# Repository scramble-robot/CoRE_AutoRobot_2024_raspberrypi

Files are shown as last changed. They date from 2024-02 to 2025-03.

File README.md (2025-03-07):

# SDカード

1. Raspberry Pi ImagerでRaspberry Pi OS Lite (64-bit,**bullseye**)をMicro SDに書き込む。Imagerの設定でユーザ名**pi**とパスワードを予め設定すること。
2. Micro SDに作成された"bootfs"ドライブ直下に`ssh`という名前のファイルを配置してSSHを有効化する。
3. OS起動後、本レポジトリの`ros2_ws`及び`service`ディレクトリをホームディレクトリ(`/home/pi/`)にコピーする。

# C620とのCAN通信

MCP2515を用いてSPIからCANを制御

- (参考) [RaspberryPiとMCP2515でCAN通信をやってみる](https://qiita.com/h-kiyo/items/d8583af13768ad67bcd0)

## ハードウェア
1Mbpsの通信を行うために、水晶振動子を**16MHz**に交換すること

## CAN-BUSの有効化
1. `/boot/config.txt`を編集してSPIとMCP2515を有効化する
    ```bash
    sudo vi /boot/config.txt
    ```

    ```
    # Uncomment some or all of these to enable the optional hardware interfaces
    #dtparam=i2c_arm=on
    #dtparam=i2s=on
    dtparam=spi=on

    # MCP2515
    dtparam=spi=on
    dtoverlay=mcp2515-can0,oscillator=16000000,interrupt=25
    dtoverlay=spi-bcm2835-overlay
    ```

2. 初期化できているか確認
    ```
    dmesg | grep mcp251x
    ```

## can-utilsのインストール
```bash
sudo apt install can-utils
```

## 通信テスト

1Mbpsでlink up

```bash
sudo ip link set can0 type can bitrate 1000000 loopback off
sudo ip link set can0 up
sudo ifconfig can0 txqueuelen 1000
sudo ifconfig
```

### 受信テスト
```bash
candump can0
```

C620と通信できていると、以下のようなデータが受信される。
```text
  can0  201   [8]  0E 16 00 00 FF FD 21 00
  can0  201   [8]  0E 16 00 00 FF FD 21 00
  can0  201   [8]  0E 16 00 00 FF BE 21 00
  can0  201   [8]  0E 16 00 00 FF FD 21 00
  can0  201   [8]  0E 16 00 00 00 3D 21 00
```

### 送信
モータ回るはず
```bash
cansend can0 200#0200000000000000
```

## systemdによるCANバスの自動有効化

1. systemdの設定
    ```bash
    sudo vi /etc/systemd/network/80-can.network
    ```

    ```text
    [Match]
    Name=can*

    [CAN]
    BitRate=1000000
    ```

    設定後、以下コマンド実行
    ```bash
    sudo systemctl enable systemd-networkd
    sudo systemctl start systemd-networkd
    ```

2. txqueuelenの自動設定
    ```bash
    sudo vi /etc/udev/rules.d/71-can-txqueuelen.rules
    ```

    ```
    SUBSYSTEM=="net", ACTION=="add|change", KERNEL=="can*", ATTR{tx_queue_len}="1000"
    ```

3. 再起動後、`ifconfig`でlink upしていることを確認

    ```
    can0: flags=193<UP,RUNNING,NOARP>  mtu 16
            unspec 00-00-00-00-00-00-00-00-00-00-00-00-00-00-00-00  txqueuelen 1000  (UNSPEC)
            RX packets 0  bytes 0 (0.0 B)
            RX errors 0  dropped 0  overruns 0  frame 0
            TX packets 0  bytes 0 (0.0 B)
            TX errors 0  dropped 0 overruns 0  carrier 0  collisions 0
    ```

## Pythonからの制御

```bash
pip install python-can
```

```python
import can
import struct
import time

bus = can.interface.Bus(bustype="socketcan", channel="can0", bitrate=1000000)

def set_current(bus, currents):
    d = [0]*8
    raw_array = [0]*4
    for i in range(4):
        v = int(round(currents[i]/20 * 16384))
        v = min(v, 16384)
        v = max(v, -16384)
        raw_array[i] = v
    b = struct.pack('>4h', *raw_array)
    msg = can.Message(arbitration_id=0x200, is_extended_id=False, data=b)
    bus.send(msg)

def parse_c620_data(msg: can.Message):
    data = struct.unpack('>hhhbb', msg.data)
    degree = data[0]/ 8192 * 360
    rpm = data[1]
    current = data[2]/16384*20
    temperature = data[3]
    return degree, rpm, current, temperature

def can_receive_callback(msg: can.Message) -> None:
    #print(msg)
    if msg.arbitration_id >= 0x201 and msg.arbitration_id < 0x204:
        degree, rpm, current, temperature = parse_c620_data(msg)
        print(f'{degree:.1f}\t{rpm:+5d}\t{current:.1f}\t{temperature:2d}')

notifier = can.Notifier(bus, [can_receive_callback])

set_current(bus, [1, -1, 0, 0])
time.sleep(1)

set_current(bus, [-1, 1, 0, 0])
time.sleep(1)

for i in range(4):
    set_current(bus, [0, 0, 0, 0])
    time.sleep(1)

notifier.stop()
bus.shutdown()
```

# サーボモータ
## ハードウェア
- 信号線はGPIO17に接続
- サーボモータの5Vは外部電源から取ること

## requirements
```bash
sudo apt install -y pigpio python3-pigpio
sudo pigpiod
sudo systemctl enable pigpiod
```

## 動作確認

```python
import pigpio

output_pin = 12 # 12 or 13

def setServoDegree(pi, output_pin, degree):
    min_width = 500
    max_width = 2500
    deg_range = 270
    output = degree / deg_range
    output *= max_width - min_width
    output += min_width
    output = int(output)
    pi.set_servo_pulsewidth(output_pin, output)

pi = pigpio.pi()
pi.set_mode(output_pin, pigpio.OUTPUT)
pi.set_servo_pulsewidth(output_pin, 0)

while True:
    print("input Duty Cyle (0 - 270)")
    degree = float(input())
    setServoDegree(pi, output_pin, degree)
```

# ROS2のインストール

Raspbian OS用の、[非公式のdebパッケージ](https://github.com/Ar-Ray-code/rpi-bullseye-ros2)を使ってインストールする

```bash
wget https://github.com/Ar-Ray-code/rpi-bullseye-ros2/releases/download/ros2-0.3.1/ros-humble-desktop-0.3.1_20221218_arm64.deb
sudo apt install ./ros-humble-desktop-0.3.1_20221218_arm64.deb
sudo pip install vcstool colcon-common-extensions

echo "source /opt/ros/humble/setup.bash" >> ~/.bashrc
source ~/.bashrc
```

## ROS2パッケージのビルド
```
cd ~/ros2_ws
colcon build --symlink-install
source install/local_setup.bash
echo "source ~/ros2_ws/install/setup.bash" >> ~/.bashrc
```

## ROS2ノードの実行
```bash
ros2 launch scramble_auto_robot hardware.launch.py
```
- この段階で下記のようなエラーが出る場合は，Raspberry piのOSのバージョンが誤っているためSDカード作成からやり直す必要がある．OSのバージョンはbullseyeを指定すること（何も指定しないと最新版のbookwormがインストールされる）
```[INFO] [launch]: All log files can be found below /home/pi/.ros/log/2024-02-11-18-34-23-302048-raspberrypi-2602
[INFO] [launch]: Default logging verbosity is set to INFO
[ERROR] [launch]: Caught exception in launch (see debug for traceback): Caught exception when trying to load file of format [py]: No module named 'rclpy._rclpy_pybind11'
The C extension '/opt/ros/humble/lib/python3.9/site-packages/_rclpy_pybind11.cpython-311-aarch64-linux-gnu.so' isn't present on the system. Please refer to 'https://docs.ros.org/en/humble/Guides/Installation-Troubleshooting.html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' for possible solutions
```

## 確認
```bash
ros2 topic pub /can_node/c620_0/target_current std_msgs/Float64 "{data: 1.0}"
ros2 topic pub /can_node/c620_0/target_current std_msgs/Float64 "{data: 0.0}"
ros2 topic pub /servo0/degree std_msgs/Float64 "{data: 0}"
ros2 topic pub /servo1/degree std_msgs/Float64 "{data: 0}"
ros2 topic echo /can_node/c620_0/rpm
```

## 自動起動
```bash
sudo ln -s /home/pi/service/scramble_auto_robot_ros2.service /etc/systemd/system
chmod 755 /home/pi/service/ros2_launch.sh
sudo systemctl enable scramble_auto_robot_ros2.service
sudo systemctl start scramble_auto_robot_ros2.service
systemctl status scramble_auto_robot_ros2.service
```

# 起動オプションの変更
1. ターミナルで`sudo raspi-config`を実行
2. "1. System Options"を選択
3. "S6 Network as Boot"でネットワーク確率までBootを待つように設定
4. "S5 Boot / Auto Login"で"Console Autologin"を選択

# SDカードのRead only化
SDカードへの書き込み中に電源を抜くとSDカードが壊れる可能性があるので、read-onlyに設定する。

参考: [Raspberry Pi で Overlay File System (read-only file system) を試す](https://qiita.com/nanbuwks/items/d5d0cfc5f94177515a6a)

1. ターミナルで`sudo raspi-config`を実行
2. "4 Performance Options Configure performance settings"
3. "P3 Overlay File System Enable/disable read-only file system"
4. 有効化して再起動

# その他
- ros2_launch.shにて`ROS_DOMAIN_ID=0`に設定しています。
- デフォルトの設定ではIPアドレスの割当はDHCPで行われます。

# Third-party license
本手順で作成した場合、以下のサードパーティ製ソフトウェアがインストールされます。
(本レポジトリに直接は含まれていません)

- Raspbian OS
- ROS2 Humble
- [rpi-bullseye-ros2](https://github.com/Ar-Ray-code/rpi-bullseye-ros2/blob/main/LICENSE) (MIT License)
- [python-can](https://pypi.org/project/python-can/) (LGPL v3)
- [pigpio](https://github.com/joan2937/pigpio/blob/master/UNLICENCE) (Unlicense)

デバッグ用
- [can-utils](https://github.com/linux-can/can-utils/tree/master/LICENSES)

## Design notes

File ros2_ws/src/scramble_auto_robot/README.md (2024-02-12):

# CoRE Automatic Robot Hardware Package

This package contains a two ros2 nodes which control hardware components

## can_node
#### Subscriber
- `/can_node/motor0/target_current` \
  Data type: Float64 \
  Data range: 0 to 20 [A]

- `/can_node/motor1/target_current` \
  Data type: Float64 \
  Data range: 0 to 20 [A]

#### Publisher
- `/can_node/motor0/rpm` \
  Data type: Float64

- `/can_node/motor1/rpm` \
  Data type: Float64

## servo_node
#### Subscriber
- `/servo0/degree` \
  Data type: Float64 \
  Data range: 0 to 270
- `/servo1/degree` \
  Data type: Float64 \
  Data range: 0 to 270

## gpio_node
#### Publisher
- `/gpio_node/in0` \
  Data type: Bool
- `/gpio_node/in1` \
  Data type: Bool
- `/gpio_node/in2` \
  Data type: Bool
- `/gpio_node/in3` \
  Data type: Bool

# launch
```bash
ros2 launch scramble_auto_robot hardware.launch.py
```

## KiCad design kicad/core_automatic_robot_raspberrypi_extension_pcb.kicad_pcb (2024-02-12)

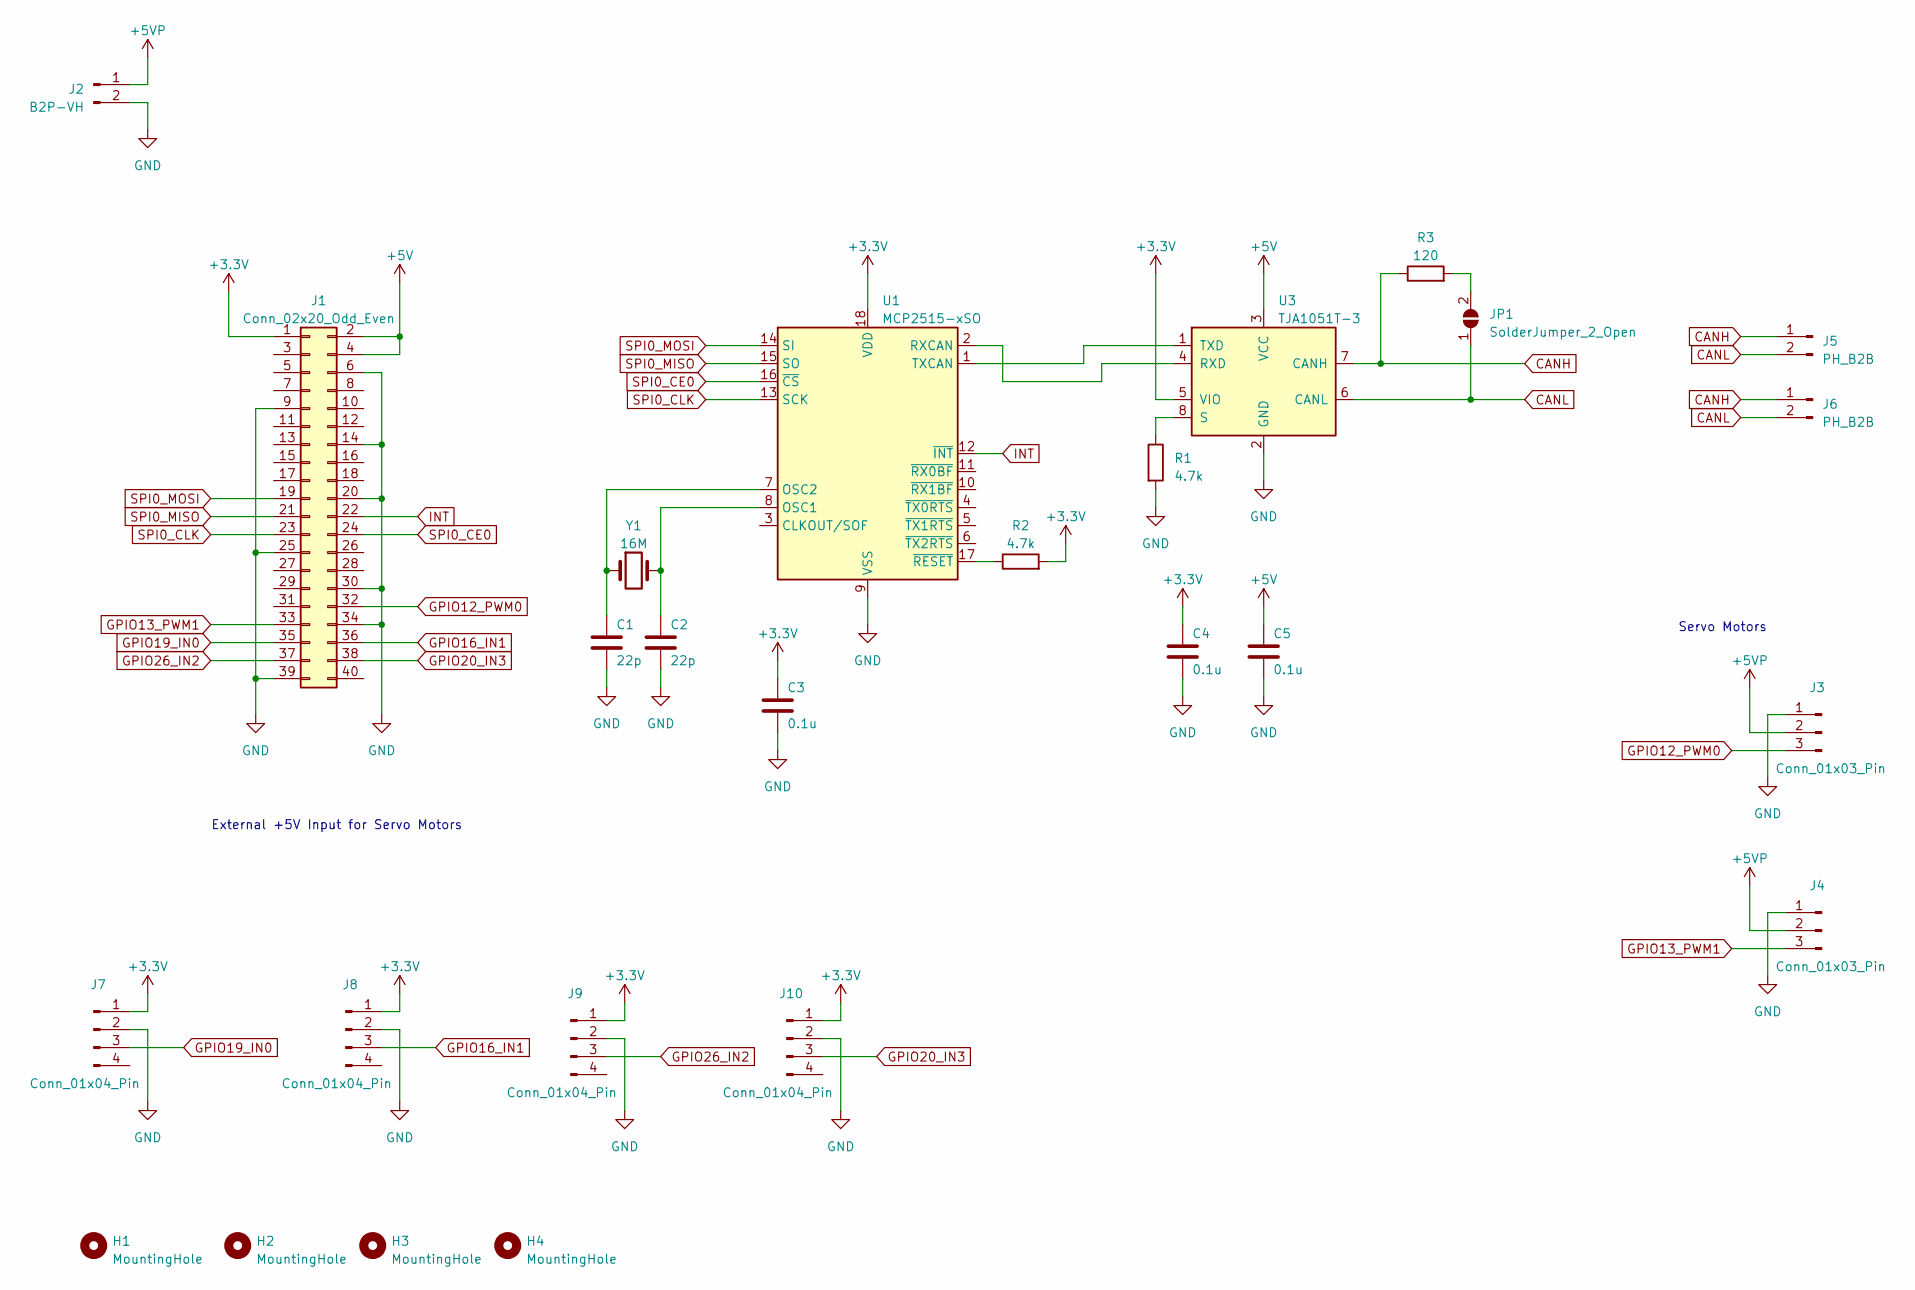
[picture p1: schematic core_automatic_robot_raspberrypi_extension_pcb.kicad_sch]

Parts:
C1, C2: 22p; C_0603_1608Metric_Pad1.08x0.95mm_HandSolder
C3, C4, C5: 0.1u; C_0603_1608Metric_Pad1.08x0.95mm_HandSolder
H1, H2, H3, H4: MountingHole; MountingHole_3.2mm_M3
J1: Conn_02x20_Odd_Even; PinHeader_2x20_P2.54mm_Vertical
J2: B2P-VH; JST_VH_B2P-VH-B_1x02_P3.96mm_Vertical
J3, J4: Conn_01x03_Pin; PinHeader_1x03_P2.54mm_Horizontal
J5, J6: PH_B2B; JST_PH_B2B-PH-K_1x02_P2.00mm_Vertical
J7, J8, J9, J10: Conn_01x04_Pin; JST_XH_B4B-XH-A_1x04_P2.50mm_Vertical
JP1: SolderJumper_2_Open; SolderJumper-2_P1.3mm_Open_Pad1.0x1.5mm
R1, R2: 4.7k; R_0603_1608Metric_Pad0.98x0.95mm_HandSolder
R3: 120; R_0603_1608Metric_Pad0.98x0.95mm_HandSolder
U1: MCP2515-xSO; SOIC-18W_7.5x11.6mm_P1.27mm
U3: TJA1051T-3; SOIC-8_3.9x4.9mm_P1.27mm
Y1: 16M; Crystal_HC49-U_Vertical

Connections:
+3.3V: C3.1, C4.1, J1.1, J7.1, J8.1, J9.1, J10.1, R2.2, U1.18 (VDD), U3.5 (VIO)
+5V: C5.1, J1.2, J1.4, U3.3 (VCC)
+5VP: J2.1, J3.2, J4.2
CANH: J5.1, J6.1, R3.1, U3.7 (CANH)
CANL: J5.2, J6.2, JP1.1 (A), U3.6 (CANL)
GND: C1.2, C2.2, C3.2, C4.2, C5.2, J1.6, J1.9, J1.14, J1.20, J1.25, J1.30, J1.34, J1.39, J2.2, J3.1, J4.1, J7.2, J8.2, J9.2, J10.2, R1.2, U1.9 (VSS), U3.2 (GND)
GPIO12_PWM0: J1.32, J3.3
GPIO13_PWM1: J1.33, J4.3
GPIO16_IN1: J1.36, J8.3
GPIO19_IN0: J1.35, J7.3
GPIO20_IN3: J1.38, J10.3
GPIO26_IN2: J1.37, J9.3
INT: J1.22, U1.12 (~INT)
unnamed: JP1.2 (B), R3.2
unnamed: C2.1, U1.8 (OSC1), Y1.2
unnamed: C1.1, U1.7 (OSC2), Y1.1
unnamed: U1.2 (RXCAN), U3.4 (RXD)
unnamed: U1.1 (TXCAN), U3.1 (TXD)
unnamed: R2.1, U1.17 (~RESET)
unnamed: R1.1, U3.8 (S)
SPI0_CE0: J1.24, U1.16 (~CS)
SPI0_CLK: J1.23, U1.13 (SCK)
SPI0_MISO: J1.21, U1.15 (SO)
SPI0_MOSI: J1.19, U1.14 (SI)

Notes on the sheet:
Servo Motors
External +5V Input for Servo Motors

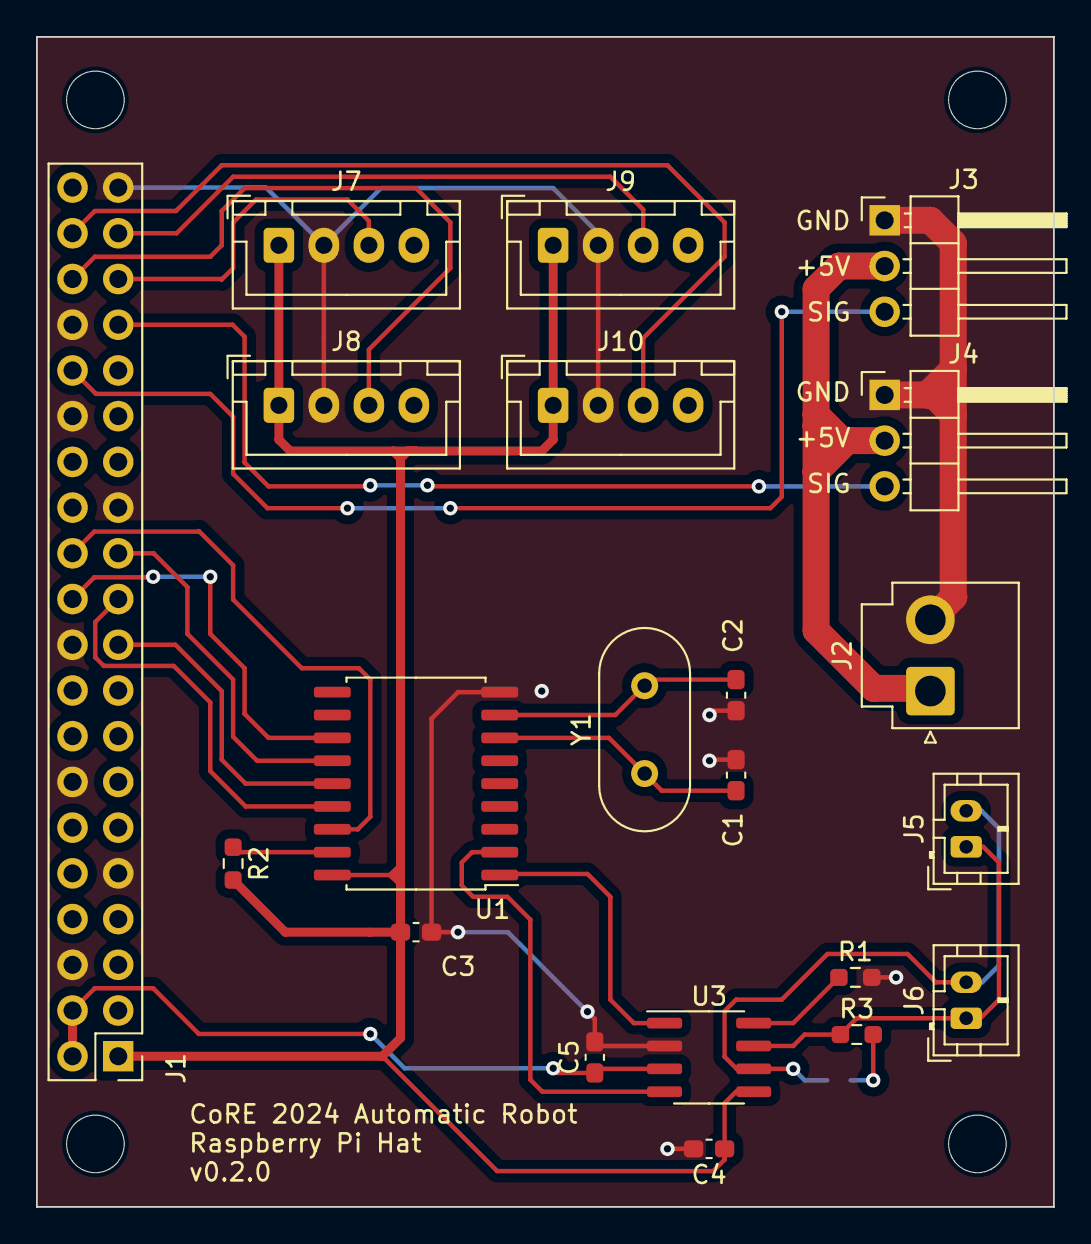
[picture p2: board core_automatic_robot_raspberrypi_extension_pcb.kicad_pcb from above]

Board: 2 copper layers, 56.5 x 65.0 mm, 26 parts (1 on the bottom side), 24 nets.

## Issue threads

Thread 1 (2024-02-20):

動作確認スクリプトのpwm指定が間違っている

Ar-Ray-code, 2024-02-20:
お世話になっております。チームStrayedCatsの洗と申します。

Readmeの [サーボモータ/動作確認](https://github.com/scramble-robot/CoRE_AutoRobot_2024_raspberrypi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) について、 `output_pin = 17` となっていますが、正しくは `output_pin = 12 # 12 or 13` です。

ご確認のほどよろしくお願いします。

Closed 2025-03-07.

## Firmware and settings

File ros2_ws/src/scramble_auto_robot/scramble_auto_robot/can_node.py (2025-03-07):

import rclpy
from std_msgs.msg import Float64, Int64, Bool

from threading import Thread
import queue
import can
import struct
import time

def c620_set_current(bus, currents):
    d = [0]*8
    raw_array = [0]*4
    for i in range(4):
        v = int(round(currents[i]/20 * 16384))
        v = min(v, 16384)
        v = max(v, -16384)
        raw_array[i] = v
    b = struct.pack('>4h', *raw_array)
    msg = can.Message(arbitration_id=0x200, is_extended_id=False, data=b)
    try:
        bus.send(msg)
    except can.exceptions.CanOperationError:
        pass

def gm6020_set_volt(bus, volts):
    d = [0]*8
    raw_array = [0]*4
    for i in range(4):
        v = volts[i]
        v = min(v, 30000)
        v = max(v, -30000)
        raw_array[i] = v
    b = struct.pack('>4h', *raw_array)
    msg = can.Message(arbitration_id=0x1ff, is_extended_id=False, data=b)
    try:
        bus.send(msg)
    except can.exceptions.CanOperationError:
        pass

def parse_c620_data(msg: can.Message):
    data = struct.unpack('>hhhbb', msg.data)
    degree = data[0]/ 8192 * 360
    rpm = data[1]
    current = data[2]/16384*20
    temperature = data[3]
    return degree, rpm, current, temperature

def parse_gm6020_data(msg: can.Message):
    data = struct.unpack('>hhhbb', msg.data)
    degree = data[0]/ 8192 * 360
    rpm = data[1]
    current = data[2]/16384*20
    temperature = data[3]
    return degree, rpm, current, temperature

exit_flag = False
c620_msg_count = [0, 0]
gm6020_msg_count = [0, 0]
interrupt_datas = [True, True, True, True]

def can_task(c620_queues, c620_rpm_publishes, gm6020_queues, gm6020_deg_publishes):
    global exit_flag
    global interrupt_datas
    bus = can.interface.Bus(bustype="socketcan", channel="can0", bitrate=1000000)
    
    def notifier(msg: can.Message) -> None:
        if msg.arbitration_id == 0x201 or msg.arbitration_id == 0x202:
            idx = msg.arbitration_id - 0x201
            c620_msg_count[idx] += 1
            if c620_msg_count[idx] >= 5:
                c620_msg_count[idx] = 0
                degree, rpm, current, temperature = parse_c620_data(msg)
                topic = Float64()
                topic.data = float(rpm)
                c620_rpm_publishes[idx].publish(topic)
        elif msg.arbitration_id == 0x205 or msg.arbitration_id == 0x206:
            idx = msg.arbitration_id - 0x205
            gm6020_msg_count[idx] += 1
            if gm6020_msg_count[idx] >= 5:
                gm6020_msg_count[idx] = 0
                degree, rpm, current, temperature = parse_gm6020_data(msg)
                topic = Float64()
                topic.data = float(degree)
                gm6020_deg_publishes[idx].publish(topic)
            
    notifier = can.Notifier(bus, [notifier])
    
    c620_target_current = [0]*4
    gm6020_target_voltage = [0]*4
    
    while not exit_flag:
        # C620
        for i, que in enumerate(c620_queues):
            if not que.empty():
                c620_target_current[i] = que.get(block=False)
        c620_set_current(bus, c620_target_current)
        
        #GM6020
        for i, que in enumerate(gm6020_queues):
            if not que.empty():
                target_voltage = que.get(block=False)
                if i == 0:
                    if (target_voltage < 0 and interrupt_datas[3]) or (target_voltage > 0 and interrupt_datas[2]):
                        target_voltage = 0
                elif i == 1:
                    if (target_voltage < 0 and interrupt_datas[0]) or (target_voltage > 0 and interrupt_datas[1]):
                        target_voltage = 0
                gm6020_target_voltage[i] = target_voltage
        gm6020_set_volt(bus, gm6020_target_voltage)
     
        time.sleep(0.001)
    
    notifier.stop()
    bus.shutdown()

def callback0(msg):
    global interrupt_datas
    interrupt_datas[0] = msg.data

def callback1(msg):
    global interrupt_datas
    interrupt_datas[1] = msg.data

def callback2(msg):
    global interrupt_datas
    interrupt_datas[2] = msg.data

def callback3(msg):
    global interrupt_datas
    interrupt_datas[3] = msg.data

def main(args=None):
    rclpy.init(args=args)

    node = rclpy.create_node('can_node')
    
    c620_queues = []
    c620_rpm_publishes = []
    
    for i in range(2):
        c620_queues.append(queue.Queue())
        p = node.create_publisher(Float64, f'~/c620_{i}/rpm', 10)
        c620_rpm_publishes.append(p)

    c620_s0 = node.create_subscription(Float64, f'~/c620_0/target_current', lambda msg: c620_queues[0].put(msg.data), 10)
    c620_s1 = node.create_subscription(Float64, f'~/c620_1/target_current', lambda msg: c620_queues[1].put(msg.data), 10)
    
    gm6020_queues = []
    gm6020_deg_publishes = []

    for i in range(2):
        gm6020_queues.append(queue.Queue())
        p = node.create_publisher(Float64, f'~/gm6020_{i}/degree', 10)
        gm6020_deg_publishes.append(p)

    gm6020_s0 = node.create_subscription(Int64, f'~/gm6020_0/target_volt', lambda msg: gm6020_queues[0].put(msg.data), 10)
    gm6020_s1 = node.create_subscription(Int64, f'~/gm6020_1/target_volt', lambda msg: gm6020_queues[1].put(msg.data), 10)
    
    interrupter_s0 = node.create_subscription(Bool, f'/gpio_node/in0', callback0, 10)
    interrupter_s1 = node.create_subscription(Bool, f'/gpio_node/in1', callback1, 10)
    interrupter_s2 = node.create_subscription(Bool, f'/gpio_node/in2', callback2, 10)
    interrupter_s3 = node.create_subscription(Bool, f'/gpio_node/in3', callback3, 10)

    task = Thread(target=can_task, args=[c620_queues, c620_rpm_publishes, gm6020_queues, gm6020_deg_publishes])
    task.start()

    rclpy.spin(node)
    
    exit_flag = True
    task.join()

    node.destroy_node()
    rclpy.shutdown()


if __name__ == '__main__':
    main()

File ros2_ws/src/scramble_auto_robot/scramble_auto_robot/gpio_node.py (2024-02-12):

import rclpy
from rclpy.publisher import Publisher
from rclpy.node import Node
from std_msgs.msg import Bool
from datetime import datetime

import pigpio

class GpioInputPublisher:
    def __init__(self, pi:pigpio.pi, clock, publisher: Publisher, pin: int):
        self.pi = pi
        self.clock = clock
        self.publisher = publisher
        self.pin = pin
        self.prev_state = False
        self.prev_pub_clock = self.clock.now()

        self.pi.set_mode(pin, pigpio.INPUT)
        self.publish(force=True)
    
    def publish(self, force=False):
        pin_state = bool(self.pi.read(self.pin))
        duration = self.clock.now() - self.prev_pub_clock
        if force or self.prev_state != pin_state or duration.nanoseconds >= 1e9:
            topic = Bool()
            topic.data = pin_state
            self.publisher.publish(topic)
            self.prev_state = pin_state
            self.prev_pub_clock = self.clock.now()

class GpioNode(Node):

    def __init__(self, pi):
        super().__init__('gpio_node')
        self.pi = pi

        self.declare_parameter('in0', 19)
        self.declare_parameter('in1', 16)
        self.declare_parameter('in2', 26)
        self.declare_parameter('in3', 20)
        
        clock = self.get_clock()
        
        self.input_publishers = []
        for i in range(4):
            pub = self.create_publisher(Bool, f'~/in{i}', 10)
            pin = self.get_parameter(f'in{i}').get_parameter_value().integer_value
            # set GPIO as input        
            self.get_logger().info(f"in{i}: {pin}")

            self.input_publishers.append( GpioInputPublisher(pi, clock, pub, pin) )
        
        self.timer = self.create_timer(0.05, self.timer_callback)
 
    def timer_callback(self):
        for in_pub in self.input_publishers:
            in_pub.publish()

    
def main(args=None):
    rclpy.init(args=args)

    pi = pigpio.pi()

    publisher = GpioNode(pi)
    rclpy.spin(publisher)
    publisher.destroy_node()
    rclpy.shutdown()


if __name__ == '__main__':
    main()

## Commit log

2025-01-07 ROS 2ノード実行時のエラーに関するトラブルシューティングを追加
2025-01-21 ROS 2ノード自動起動がうまくいかない問題に対する修正
2025-01-21 フォトインタラプタが反応してもモータが止まらない問題を修正
2025-03-07 動作確認スクリプトのpwm指定が間違っている件の修正
